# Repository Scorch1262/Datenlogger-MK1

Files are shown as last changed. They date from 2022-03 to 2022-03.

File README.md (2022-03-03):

# Datenlogger-MK1

 Funktionen (Software V4.0) [F]:
- MCC UART Funktion
- MCC SPI Funktion
- MCC Flash (SD-Karten) Funktion
- MCC FATfs Funktion
- LED Definiert
- Status LED1 für den Abbruch des schreibvorgangs wegen fehlendem Medium.
- 32MHz
- Erzeugt eine .txt Datei und schreibt Messwerte und eine Zahl hinein
- In einer Endlosscheife immer in der nächsten Zeile
- Auslesen des Sensors (LPS33HW)
- Auslesen des ADCs (MCP3221)
- Auslesen der RTC (MCP79410)
- Schreiben der Werte auf die SD-Karte
  - Schreiben der Daten in Datumsabhängige dateien
  - beibehalten des Richtigen Datums/Uhrzeit

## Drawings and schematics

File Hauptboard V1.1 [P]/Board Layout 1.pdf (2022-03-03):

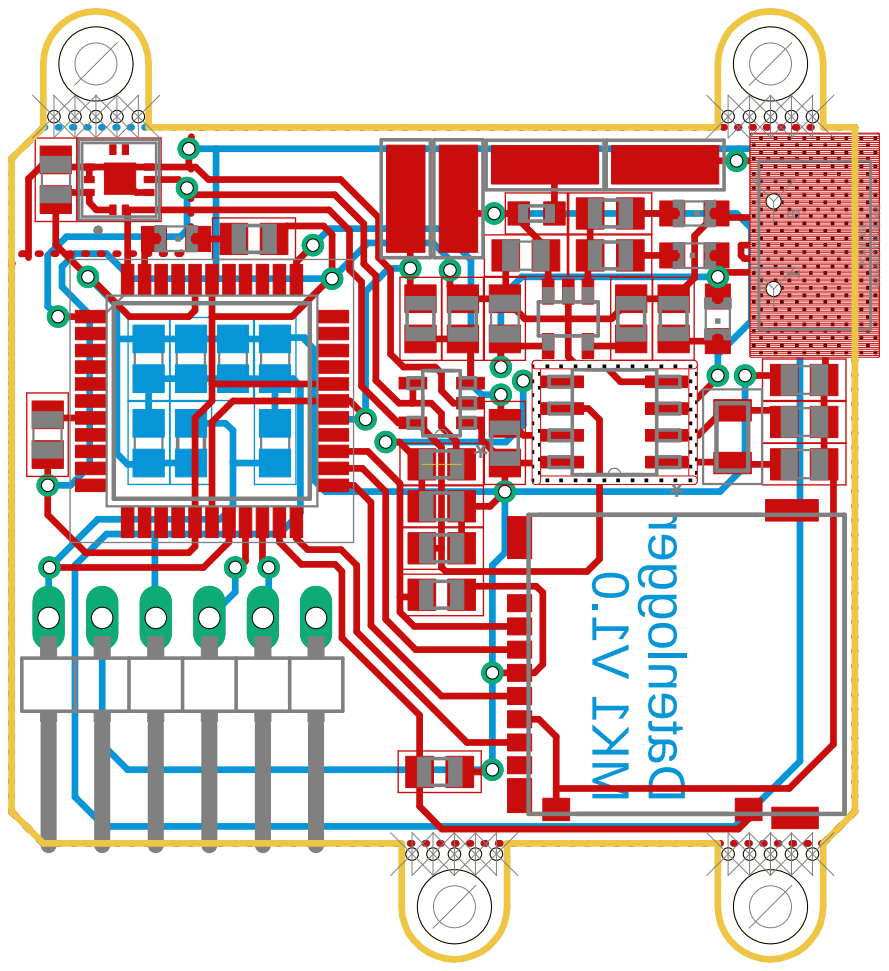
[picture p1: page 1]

Datenlogger MK1 V1.0 * * 1 5 PCB EDGE CONNECTOR EDGE

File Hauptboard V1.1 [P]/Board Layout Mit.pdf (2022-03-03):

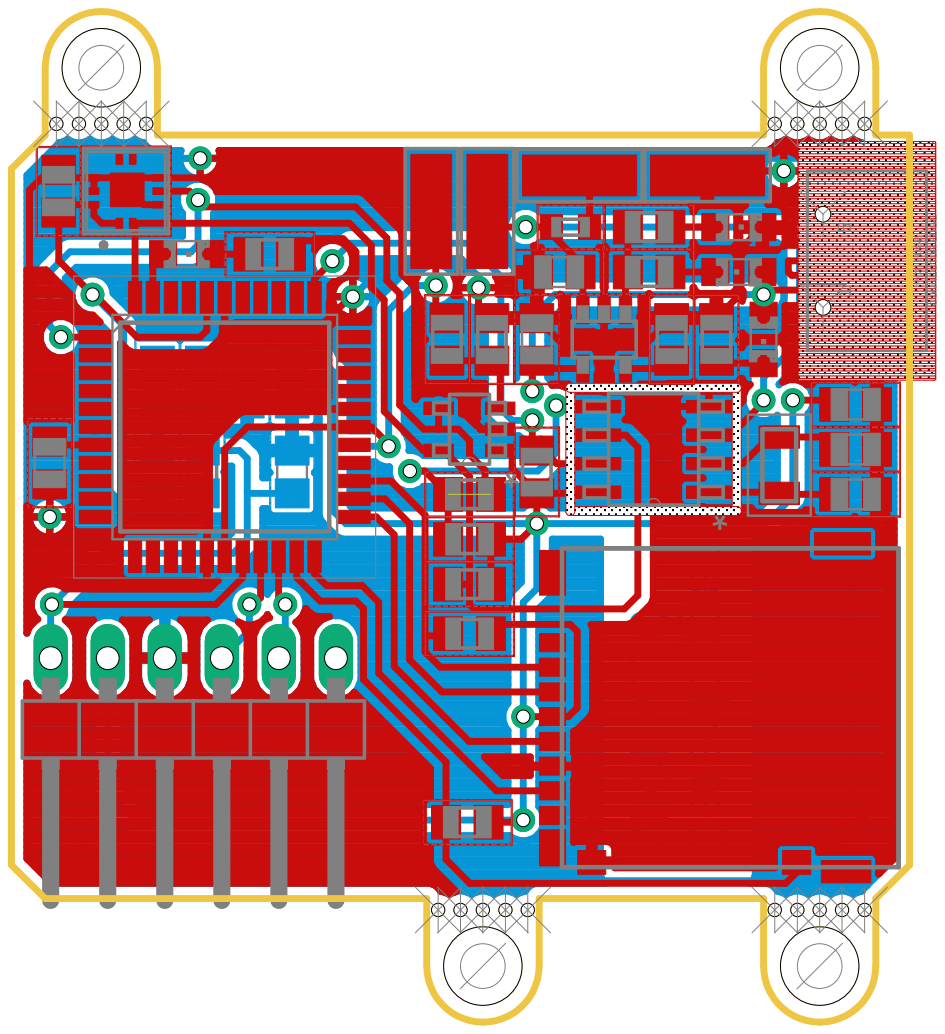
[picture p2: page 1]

Datenlogger MK1 V1.0 * * 1 5 PCB EDGE CONNECTOR EDGE

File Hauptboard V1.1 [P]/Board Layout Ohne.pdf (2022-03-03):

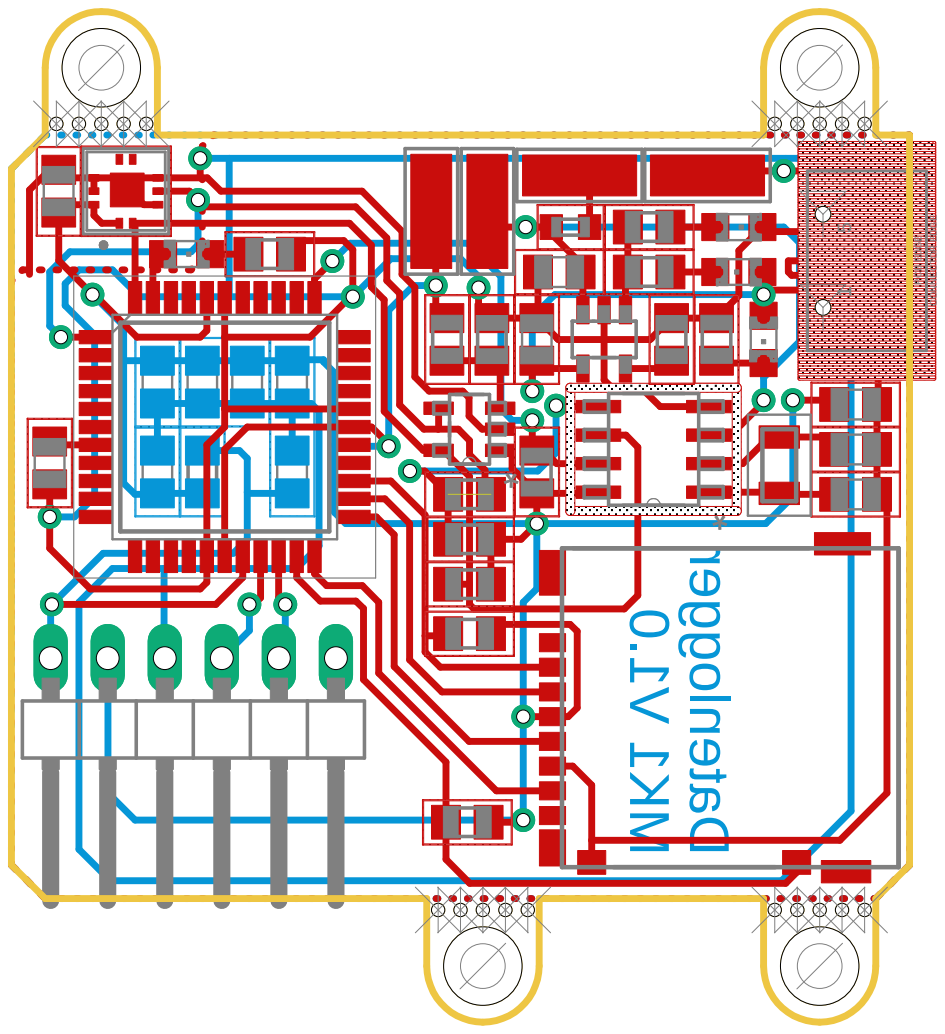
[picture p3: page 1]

Datenlogger MK1 V1.0 * * 1 5 PCB EDGE CONNECTOR EDGE

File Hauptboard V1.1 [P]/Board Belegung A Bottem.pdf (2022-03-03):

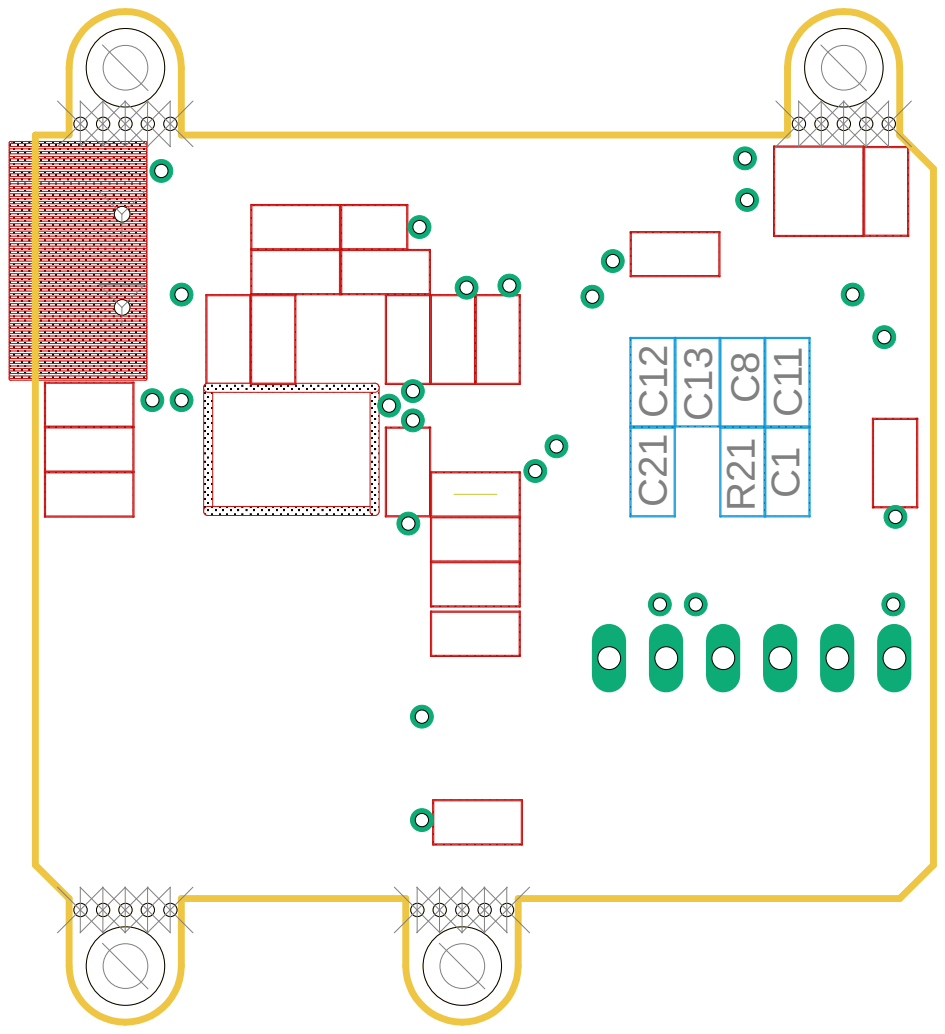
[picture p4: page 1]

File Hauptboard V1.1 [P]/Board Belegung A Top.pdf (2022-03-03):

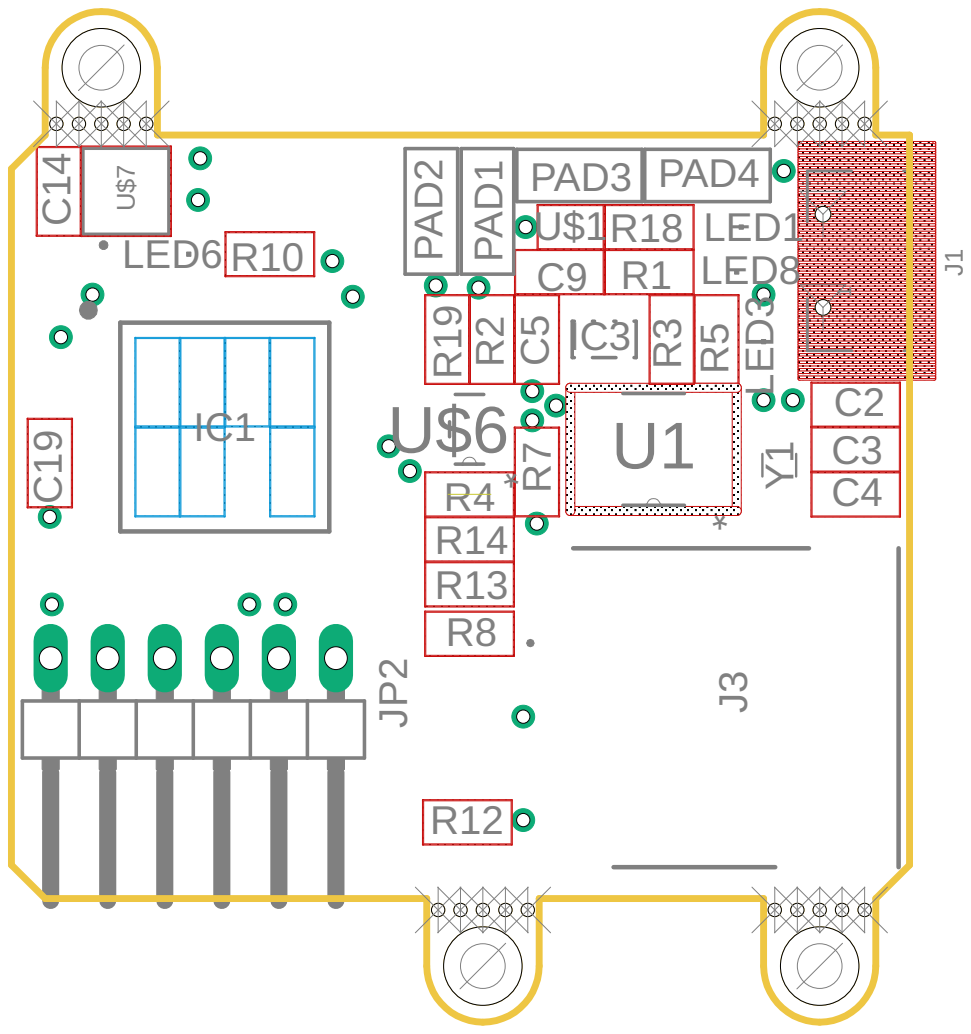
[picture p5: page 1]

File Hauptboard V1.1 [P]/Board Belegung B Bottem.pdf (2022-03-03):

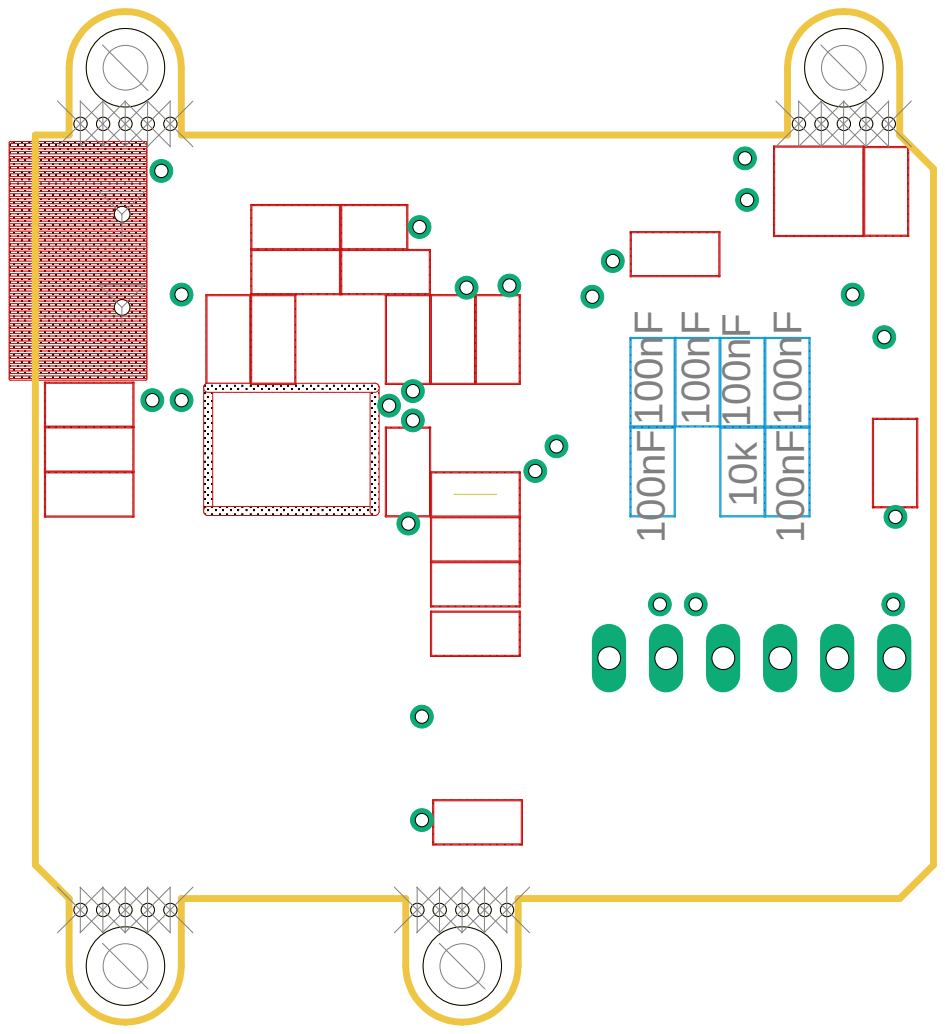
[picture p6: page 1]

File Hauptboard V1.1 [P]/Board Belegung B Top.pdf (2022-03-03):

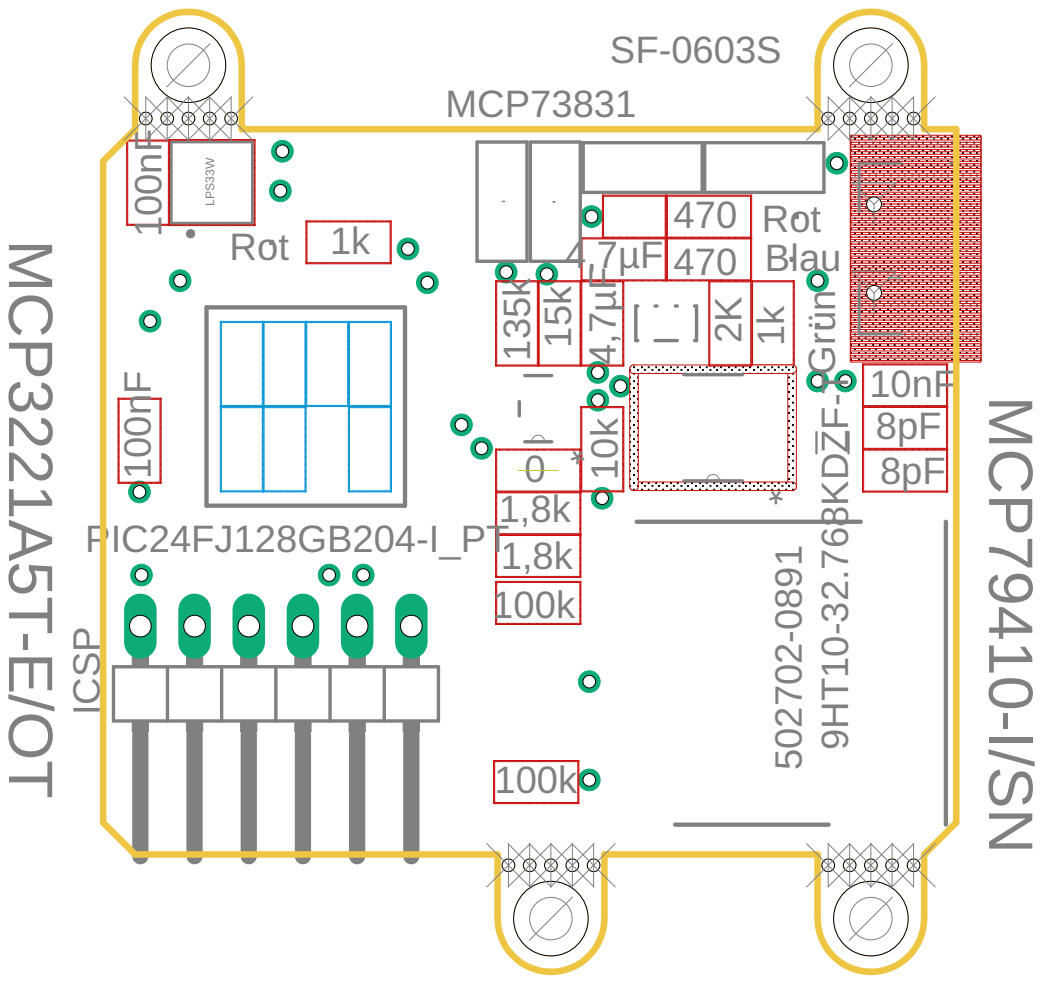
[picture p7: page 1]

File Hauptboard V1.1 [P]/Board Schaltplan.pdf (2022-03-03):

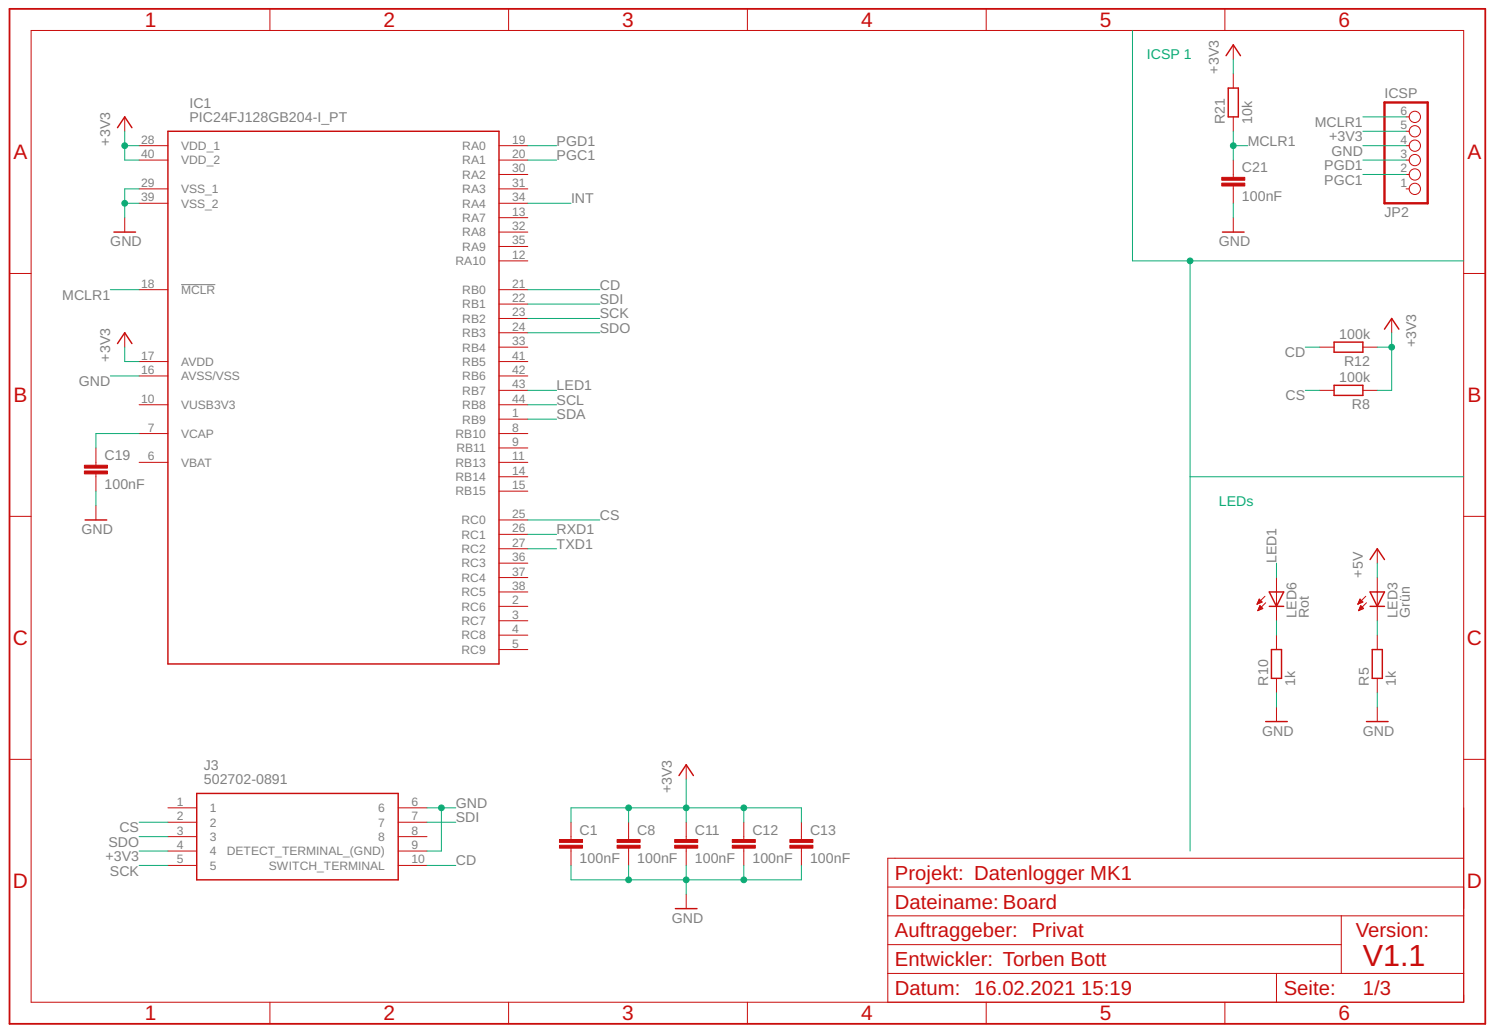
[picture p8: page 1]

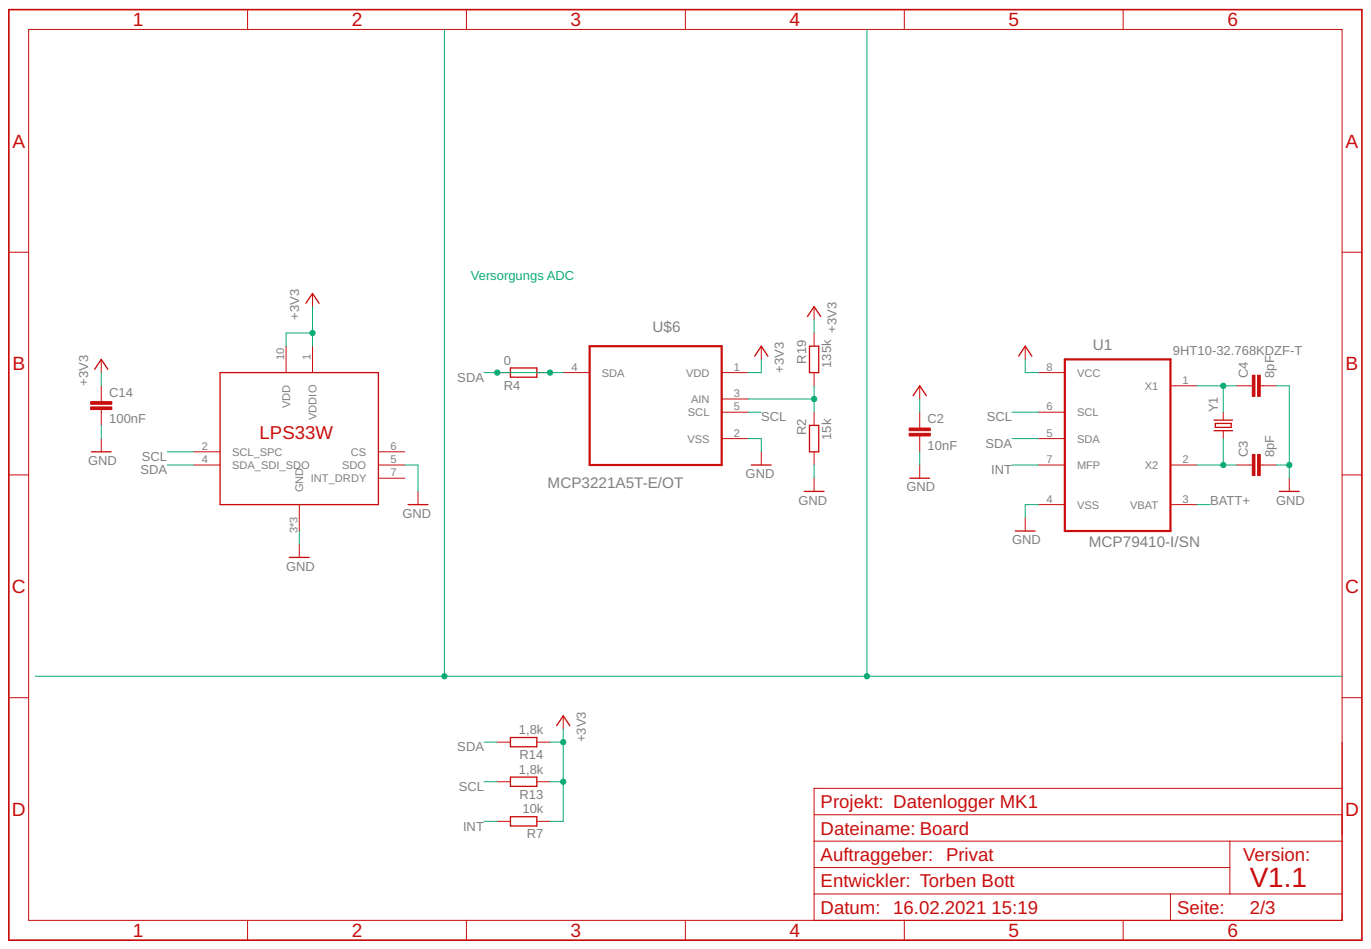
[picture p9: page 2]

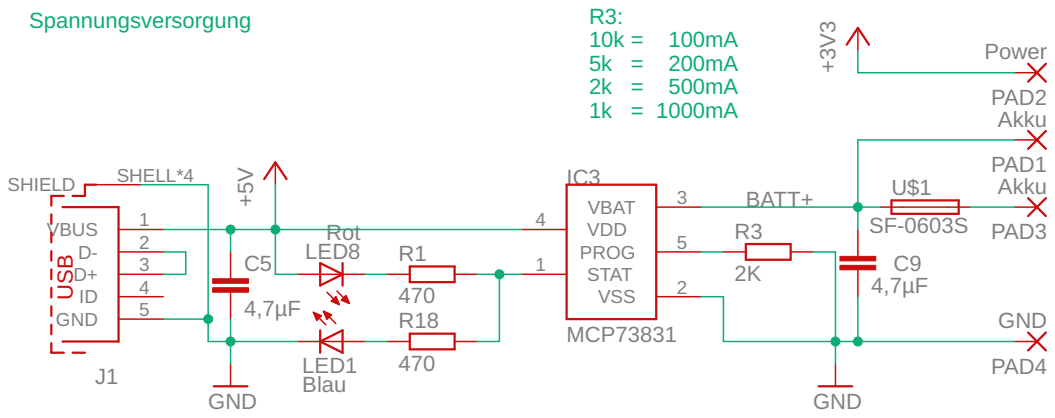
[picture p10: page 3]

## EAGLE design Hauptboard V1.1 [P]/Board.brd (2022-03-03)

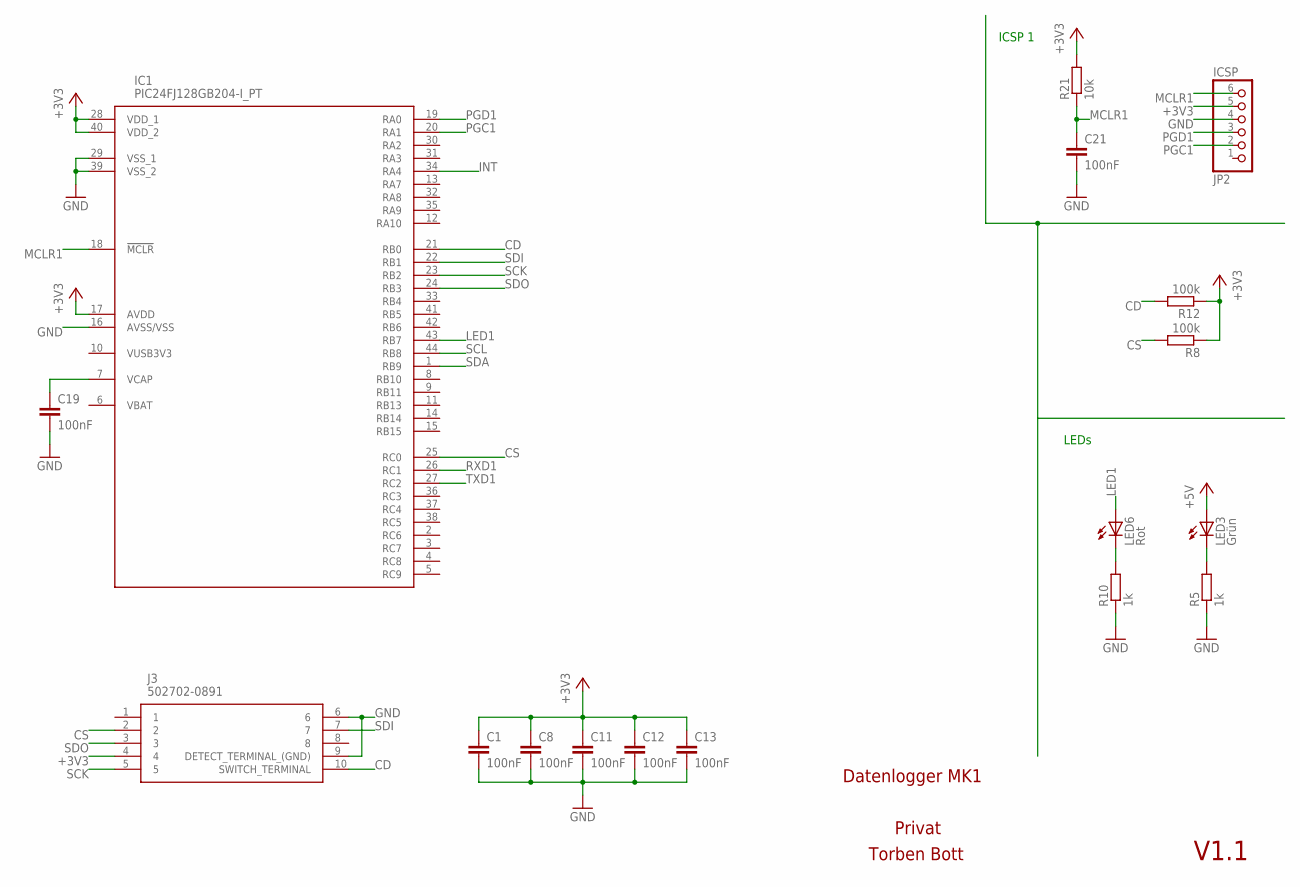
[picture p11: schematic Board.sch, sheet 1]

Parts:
C1, C8, C11, C12, C13, C19, C21: 100nF; C0805
IC1: PIC24FJ128GB204-I_PT; QFP80P1200X1200X120-44N
J3: 502702-0891
JP2: ICSP; 1X06/90
LED3: Grün; CHIPLED_0805
LED6: Rot; CHIPLED_0805
R5, R10: 1k; R0805
R8, R12: 100k; R0805
R21: 10k; R0805

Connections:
+3V3: C1.1, C8.1, C11.1, C12.1, C13.1, IC1.17 (AVDD), IC1.28 (VDD_1), IC1.40 (VDD_2), J3.4, JP2.5, R8.1, R12.1, R21.2; also elsewhere on the board
+5V: LED3.A; also elsewhere on the board
CD: IC1.21 (RB0), J3.10 (SWITCH_TERMINAL), R12.2
CS: IC1.25 (RC0), J3.2, R8.2
GND: C1.2, C8.2, C11.2, C12.2, C13.2, C19.2, C21.2, IC1.16 (AVSS/VSS), IC1.29 (VSS_1), IC1.39 (VSS_2), J3.6, J3.9 (DETECT_TERMINAL_(GND)), JP2.4, R5.1, R10.1; also elsewhere on the board
INT: IC1.34 (RA4); also elsewhere on the board
LED1: IC1.43 (RB7), LED6.A
MCLR1: C21.1, IC1.18 (!MCLR), JP2.6, R21.1
unnamed: LED3.C, R5.2
unnamed: LED6.C, R10.2
unnamed: C19.1, IC1.7 (VCAP)
PGC1: IC1.20 (RA1), JP2.2
PGD1: IC1.19 (RA0), JP2.3
RXD1: IC1.26 (RC1)
SCK: IC1.23 (RB2), J3.5
SCL: IC1.44 (RB8); also elsewhere on the board
SDA: IC1.1 (RB9); also elsewhere on the board
SDI: IC1.22 (RB1), J3.7
SDO: IC1.24 (RB3), J3.3
TXD1: IC1.27 (RC2)

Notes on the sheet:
ICSP 1
LEDs
Datenlogger MK1
Privat
Torben Bott
V1.1

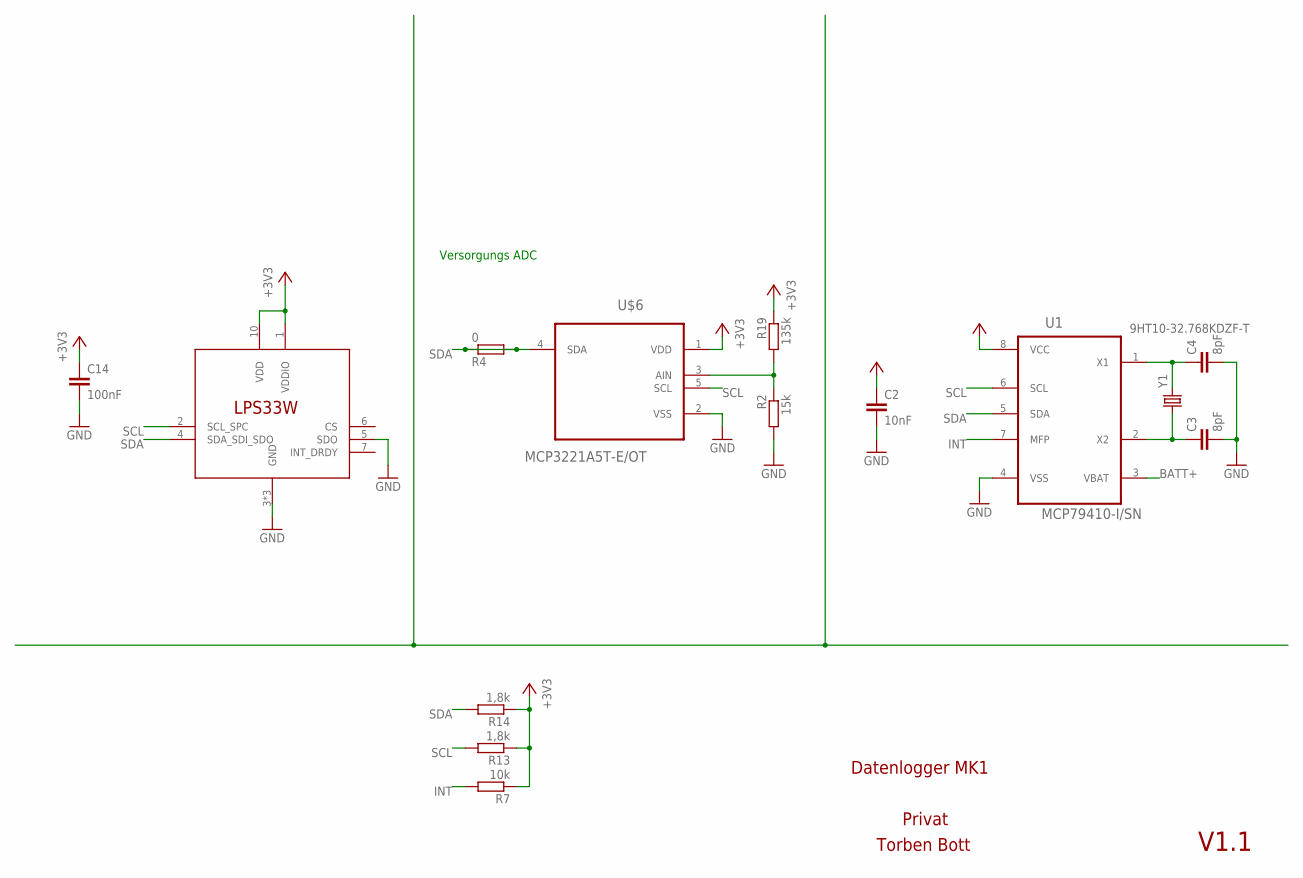
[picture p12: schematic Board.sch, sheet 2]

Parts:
C2: 10nF; C0805
C3, C4: 8pF; C0805
C14: 100nF; C0805
R2: 15k; R0805
R4: 0; R0805
R7: 10k; R0805
R13, R14: 1,8k; R0805
R19: 135k; R0805
U1: MCP79410-I/SN; SOIC127P600X175-8N
U$6: MCP3221A5T-E/OT; SOT95P270X145-5N
U$7: LPS33W; CCLGA10L
Y1: 9HT10-32.768KDZF-T; 9HT1032768KEZFT

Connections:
+3V3: C2.1, C14.1, R7.1, R13.1, R14.1, R19.1, U1.8 (VCC), U$6.1 (VDD), U$7.1 (VDDIO), U$7.10 (VDD); also elsewhere on the board
BATT+: U1.3 (VBAT); also elsewhere on the board
GND: C2.2, C3.2, C4.2, C14.2, R2.2, U1.4 (VSS), U$6.2 (VSS), U$7.3 (GND), U$7.5 (SDO), U$7.8 (GND), U$7.9 (GND); also elsewhere on the board
INT: R7.2, U1.7 (MFP); also elsewhere on the board
unnamed: C3.1, U1.2 (X2), Y1.1
unnamed: C4.1, U1.1 (X1), Y1.2
unnamed: R2.1, R19.2, U$6.3 (AIN)
SCL: R13.2, U1.6 (SCL), U$6.5 (SCL), U$7.2 (SCL_SPC); also elsewhere on the board
SDA: R4.1, R4.2, R14.2, U1.5 (SDA), U$6.4 (SDA), U$7.4 (SDA_SDI_SDO); also elsewhere on the board

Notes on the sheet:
Datenlogger MK1
Privat
Torben Bott
Versorgungs ADC
V1.1

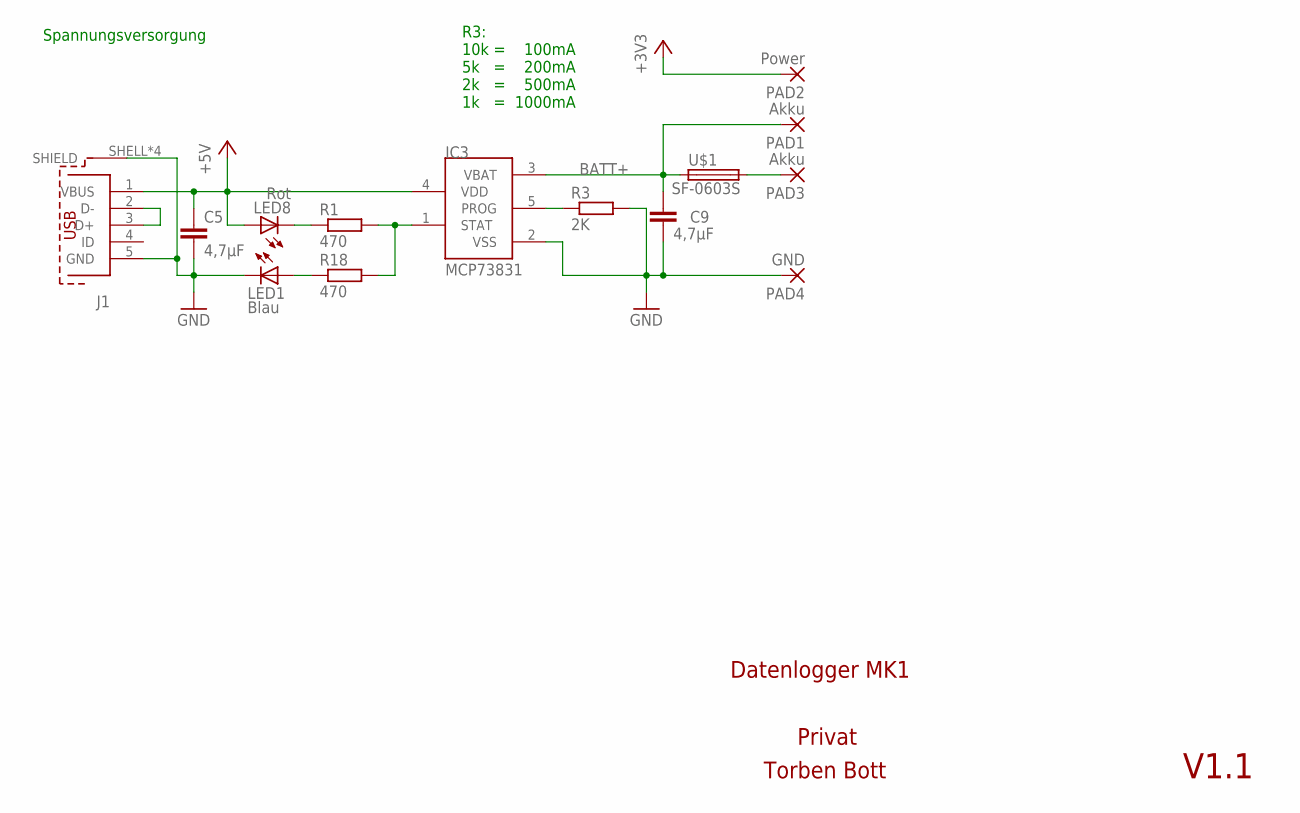
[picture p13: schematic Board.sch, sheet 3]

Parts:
C5, C9: 4,7µF; C0805
IC3: MCP73831; SOT23-5L
J1: 629105136821
LED1: Blau; CHIPLED_0805
LED8: Rot; CHIPLED_0805
PAD1, PAD3: Akku; 5-1,8
PAD2: Power; 5-1,8
PAD4: GND; 5-1,8
R1, R18: 470; R0805
R3: 2K; R0805
U$1: SF-0603S; R0603

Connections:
+3V3: PAD2.1; also elsewhere on the board
+5V: C5.1, IC3.4 (VDD), J1.1 (VBUS), LED8.A; also elsewhere on the board
BATT+: C9.1, IC3.3 (VBAT), PAD1.1, U$1.1; also elsewhere on the board
GND: C5.2, C9.2, IC3.2 (VSS), J1.5 (GND), J1.SHELL (SHIELD), J1.SHELL1 (SHIELD), J1.SHELL2 (SHIELD), J1.SHELL3 (SHIELD), LED1.C, PAD4.1, R3.2; also elsewhere on the board
unnamed: LED8.C, R1.1
unnamed: IC3.5 (PROG), R3.1
unnamed: PAD3.1, U$1.2
unnamed: LED1.A, R18.1
unnamed: IC3.1 (STAT), R1.2, R18.2
unnamed: J1.2 (D-), J1.3 (D+)

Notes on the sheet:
Datenlogger MK1
Privat
Torben Bott
Spannungsversorgung
R3: 10k = 100mA 5k = 200mA 2k = 500mA 1k = 1000mA
V1.1

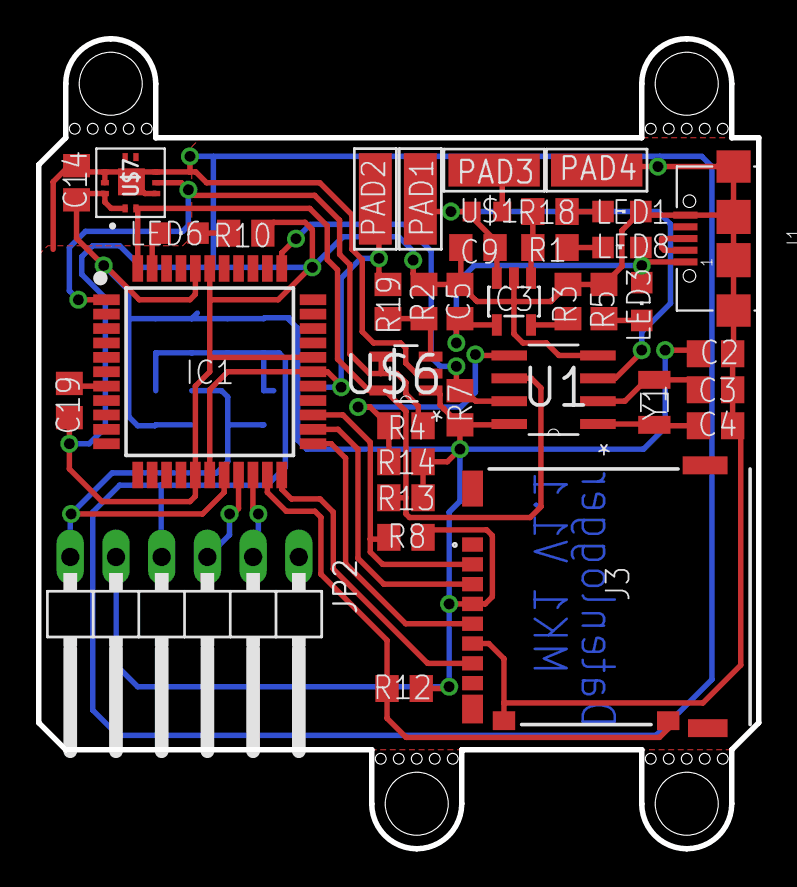
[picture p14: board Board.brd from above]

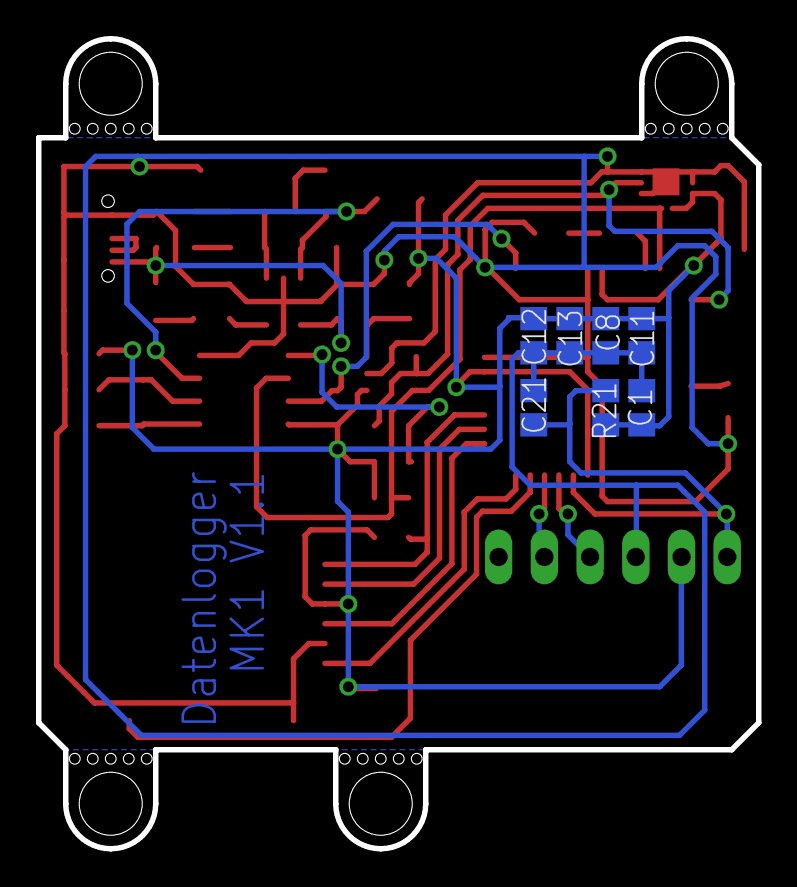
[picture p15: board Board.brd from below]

Board: 2 copper layers, 40.0 x 45.0 mm, 45 parts (7 on the bottom side), 28 nets.

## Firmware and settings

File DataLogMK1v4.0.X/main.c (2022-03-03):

/**
  Generated main.c file from MPLAB Code Configurator

  @Company
    Microchip Technology Inc.

  @File Name
    main.c

  @Summary
    This is the generated main.c using PIC24 / dsPIC33 / PIC32MM MCUs.

  @Description
    This source file provides main entry point for system initialization and application code development.
    Generation Information :
        Product Revision  :  PIC24 / dsPIC33 / PIC32MM MCUs - 1.170.0
        Device            :  PIC24FJ128GB204
    The generated drivers are tested against the following:
        Compiler          :  XC16 v1.61
        MPLAB 	          :  MPLAB X v5.45
*/

/*
    (c) 2020 Microchip Technology Inc. and its subsidiaries. You may use this
    software and any derivatives exclusively with Microchip products.

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
    IN NO EVENT WILL MICROCHIP BE LIABLE FOR ANY INDIRECT, SPECIAL, PUNITIVE,
    INCIDENTAL OR CONSEQUENTIAL LOSS, DAMAGE, COST OR EXPENSE OF ANY KIND
    WHATSOEVER RELATED TO THE SOFTWARE, HOWEVER CAUSED, EVEN IF MICROCHIP HAS
    BEEN ADVISED OF THE POSSIBILITY OR THE DAMAGES ARE FORESEEABLE. TO THE
    FULLEST EXTENT ALLOWED BY LAW, MICROCHIP'S TOTAL LIABILITY ON ALL CLAIMS IN
    ANY WAY RELATED TO THIS SOFTWARE WILL NOT EXCEED THE AMOUNT OF FEES, IF ANY,
    THAT YOU HAVE PAID DIRECTLY TO MICROCHIP FOR THIS SOFTWARE.

    MICROCHIP PROVIDES THIS SOFTWARE CONDITIONALLY UPON YOUR ACCEPTANCE OF THESE
    TERMS.
*/

/**
  Section: Included Files
*/
#define FCY 32000000UL 
#include <assert.h>
#include <stdbool.h>
#include "mcc_generated_files/system.h"
#include <stdio.h>
#include <stdlib.h>
#include <libpic30.h>
#include <xc.h>
#include <string.h>
#include "mcc_generated_files/mcc.h"
#include "mcc_generated_files/fatfs/fatfs.h"
#include "command.h"
#include "mcp3221.h"
#include "mcp79410.h"
#include "lps33hw.h"

#if defined(__dsPIC33E__)
	#include <p33exxxx.h>
#elif defined(__dsPIC33F__)
	#include <p33fxxxx.h>
#elif defined(__dsPIC30F__)
	#include <p30fxxxx.h>
#elif defined(__PIC24E__)
	#include <p24exxxx.h>
#elif defined(__PIC24H__)
	#include <p24hxxxx.h>
#elif defined(__PIC24F__) || defined(__PIC24FK__)
	#include <p24fxxxx.h>
#endif

uint8_t day;                                                    // definiert "day"
uint8_t month;                                                  // definiert "month" 
uint8_t year;                                                   // definiert "year"       
uint8_t hour;                                                   // definiert "hour"
uint8_t min;                                                    // definiert "min"
uint8_t sec;                                                    // definiert "sec"
uint8_t count = 0;                                              // definiert "count" 
float temperatur;                                               // definiert "temperatur"
float luftdruck;                                                // defienert "luftdruck"
float volt_Anz;                                                 // definiert "volt_Anz"

/*
                         Main application
 */
int main(void){                                                 // "main"
    SYSTEM_Initialize();                                        // initialize the device
    __delay_ms(500);
    LPS33HW_Init();                                             // initialize den Sensor (LPS33HW)
    
    day = 0x06;                                                 // schreibt "0x04" in "day"
    month = 0x03;                                               // schreibt "0x03" in "month"
    year = 0x21;                                                // schreibt "0x21" in "year"
    hour = 0x09;                                                // schreibt "0x19" in "hour"
    min = 0x17;                                                 // schreibt "0x10" in "min"    
    //MCP79410_set_date_time(day,month,year,hour,min);          // schreibt "day","month","year","hour","min" an RTC

    while(1){                                                   // Endlosschleife
        MCP79410_get_date(&day,&month,&year);                   // ließt "day","month","year" von RTC aus
        MCP79410_get_time(&hour,&min,&sec);                     // ließt "hour","min","sec" von RTC aus
        volt_Anz = MCP3221_GetValue();                          // schreibt "MCP3221_GetValue" in "volt_Anz" 
        temperatur = LPS33HW_temp_GetValue();                   // schreibt ergebnis von "LPS33HW_temp_GetValue" in "temperatur"
        luftdruck = LPS33HW_press_GetValue();                   // schreibt ergebnis von "LPS33HW_press_GetValue" in "luftdruck"
        FatFs_Tasks();                                          // ruft "FatFs_Tasks" auf
        count = count +1;                                       // "count" + 1
        __delay_ms(1000);                                       // warte 1000ms
    }                                                           // 
    return 1;                                                   // 
}                                                               // 
/**
 End of File
*/

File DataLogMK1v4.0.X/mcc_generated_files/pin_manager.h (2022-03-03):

/**
  PIN MANAGER Generated Driver File

  @Company:
    Microchip Technology Inc.

  @File Name:
    pin_manager.h

  @Summary:
    This is the generated manager file for the PIC24 / dsPIC33 / PIC32MM MCUs device.  This manager
    configures the pins direction, initial state, analog setting.
    The peripheral pin select, PPS, configuration is also handled by this manager.

  @Description:
    This source file provides implementations for PIN MANAGER.
    Generation Information :
        Product Revision  :  PIC24 / dsPIC33 / PIC32MM MCUs - 1.170.0
        Device            :  PIC24FJ128GB204
    The generated drivers are tested against the following:
        Compiler          :  XC16 v1.61
        MPLAB 	          :  MPLAB X v5.45
*/

/*
    (c) 2020 Microchip Technology Inc. and its subsidiaries. You may use this
    software and any derivatives exclusively with Microchip products.

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
    IN NO EVENT WILL MICROCHIP BE LIABLE FOR ANY INDIRECT, SPECIAL, PUNITIVE,
    INCIDENTAL OR CONSEQUENTIAL LOSS, DAMAGE, COST OR EXPENSE OF ANY KIND
    WHATSOEVER RELATED TO THE SOFTWARE, HOWEVER CAUSED, EVEN IF MICROCHIP HAS
    BEEN ADVISED OF THE POSSIBILITY OR THE DAMAGES ARE FORESEEABLE. TO THE
    FULLEST EXTENT ALLOWED BY LAW, MICROCHIP'S TOTAL LIABILITY ON ALL CLAIMS IN
    ANY WAY RELATED TO THIS SOFTWARE WILL NOT EXCEED THE AMOUNT OF FEES, IF ANY,
    THAT YOU HAVE PAID DIRECTLY TO MICROCHIP FOR THIS SOFTWARE.

    MICROCHIP PROVIDES THIS SOFTWARE CONDITIONALLY UPON YOUR ACCEPTANCE OF THESE
    TERMS.
*/

#ifndef _PIN_MANAGER_H
#define _PIN_MANAGER_H
/**
    Section: Includes
*/
#include <xc.h>

/**
    Section: Device Pin Macros
*/
/**
  @Summary
    Sets the GPIO pin, RB0, high using LATB0.

  @Description
    Sets the GPIO pin, RB0, high using LATB0.

  @Preconditions
    The RB0 must be set to an output.

  @Returns
    None.

  @Param
    None.

  @Example
    <code>
    // Set RB0 high (1)
    SDCard_CD_SetHigh();
    </code>

*/
#define SDCard_CD_SetHigh()          (_LATB0 = 1)
/**
  @Summary
    Sets the GPIO pin, RB0, low using LATB0.

  @Description
    Sets the GPIO pin, RB0, low using LATB0.

  @Preconditions
    The RB0 must be set to an output.

  @Returns
    None.

  @Param
    None.

  @Example
    <code>
    // Set RB0 low (0)
    SDCard_CD_SetLow();
    </code>

*/
#define SDCard_CD_SetLow()           (_LATB0 = 0)
/**
  @Summary
    Toggles the GPIO pin, RB0, using LATB0.

  @Description
    Toggles the GPIO pin, RB0, using LATB0.

  @Preconditions
    The RB0 must be set to an output.

  @Returns
    None.

  @Param
    None.

  @Example
    <code>
    // Toggle RB0
    SDCard_CD_Toggle();
    </code>

*/
#define SDCard_CD_Toggle()           (_LATB0 ^= 1)
/**
  @Summary
    Reads the value of the GPIO pin, RB0.

  @Description
    Reads the value of the GPIO pin, RB0.

  @Preconditions
    None.

  @Returns
    None.

  @Param
    None.

  @Example
    <code>
    uint16_t portValue;

    // Read RB0
    postValue = SDCard_CD_GetValue();
    </code>

*/
#define SDCard_CD_GetValue()         _RB0
/**
  @Summary
    Configures the GPIO pin, RB0, as an input.

  @Description
    Configures the GPIO pin, RB0, as an input.

  @Preconditions
    None.

  @Returns
    None.

  @Param
    None.

  @Example
    <code>
    // Sets the RB0 as an input
    SDCard_CD_SetDigitalInput();
    </code>

*/
#define SDCard_CD_SetDigitalInput()  (_TRISB0 = 1)
/**
  @Summary
    Configures the GPIO pin, RB0, as an output.

  @Description
    Configures the GPIO pin, RB0, as an output.

  @Preconditions
    None.

  @Returns
    None.

  @Param
    None.

  @Example
    <code>
    // Sets the RB0 as an output
    SDCard_CD_SetDigitalOutput();
    </code>

*/
#define SDCard_CD_SetDigitalOutput() (_TRISB0 = 0)
/**
  @Summary
    Sets the GPIO pin, RB1, high using LATB1.

  @Description
    Sets the GPIO pin, RB1, high using LATB1.

  @Preconditions
    The RB1 must be set to an output.

  @Returns
    None.

  @Param
    None.

  @Example
    <code>
    // Set RB1 high (1)
    SDI1_SetHigh();
    </code>

*/
#define SDI1_SetHigh()          (_LATB1 = 1)
/**
  @Summary
    Sets the GPIO pin, RB1, low using LATB1.

  @Description
    Sets the GPIO pin, RB1, low using LATB1.

  @Preconditions
    The RB1 must be set to an output.

  @Returns
    None.

  @Param
    None.

  @Example
    <code>
    // Set RB1 low (0)
    SDI1_SetLow();
    </code>

*/
#define SDI1_SetLow()           (_LATB1 = 0)
/**
  @Summary
    Toggles the GPIO pin, RB1, using LATB1.

  @Description
    Toggles the GPIO pin, RB1, using LATB1.

  @Preconditions
    The RB1 must be set to an output.

  @Returns
    None.

  @Param
    None.

  @Example
    <code>
    // Toggle RB1
    SDI1_Toggle();
    </code>

*/
#define SDI1_Toggle()           (_LATB1 ^= 1)
/**
  @Summary
    Reads the value of the GPIO pin, RB1.

  @Description
    Reads the value of the GPIO pin, RB1.

  @Preconditions
    None.

  @Returns
    None.

  @Param
    None.

  @Example
    <code>
    uint16_t portValue;

    // Read RB1
    postValue = SDI1_GetValue();
    </code>

*/
#define SDI1_GetValue()         _RB1
/**
  @Summary
    Configures the GPIO pin, RB1, as an input.

  @Description
    Configures the GPIO pin, RB1, as an input.

  @Preconditions
    None.

  @Returns
    None.

  @Param
    None.

  @Example
    <code>
    // Sets the RB1 as an input
    SDI1_SetDigitalInput();
    </code>

*/
#define SDI1_SetDigitalInput()  (_TRISB1 = 1)
/**
  @Summary
    Configures the GPIO pin, RB1, as an output.

  @Description
    Configures the GPIO pin, RB1, as an output.

  @Preconditions
    None.

  @Returns
    None.

  @Param
    None.

  @Example
    <code>
    // Sets the RB1 as an output
    SDI1_SetDigitalOutput();
    </code>

*/
#define SDI1_SetDigitalOutput() (_TRISB1 = 0)
/**
  @Summary
    Sets the GPIO pin, RB2, high using LATB2.

  @Description
    Sets the GPIO pin, RB2, high using LATB2.

  @Preconditions
    The RB2 must be set to an output.

  @Returns
    None.

  @Param
    None.

  @Example
    <code>
    // Set RB2 high (1)
    SCK1OUT_SetHigh();
    </code>

*/
#define SCK1OUT_SetHigh()          (_LATB2 = 1)
/**
  @Summary
    Sets the GPIO pin, RB2, low using LATB2.

  @Description
    Sets the GPIO pin, RB2, low using LATB2.

  @Preconditions
    The RB2 must be set to an output.

  @Returns
    None.

  @Param
    None.

  @Example
    <code>
    // Set RB2 low (0)
    SCK1OUT_SetLow();
    </code>

*/
#define SCK1OUT_SetLow()           (_LATB2 = 0)
/**
  @Summary
    Toggles the GPIO pin, RB2, using LATB2.

  @Description
    Toggles the GPIO pin, RB2, using LATB2.

  @Preconditions
    The RB2 must be set to an output.

  @Returns
    None.

  @Param
    None.

  @Example
    <code>
    // Toggle RB2
    SCK1OUT_Toggle();
    </code>
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

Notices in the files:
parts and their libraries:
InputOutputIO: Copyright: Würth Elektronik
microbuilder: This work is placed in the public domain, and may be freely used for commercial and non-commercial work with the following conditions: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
